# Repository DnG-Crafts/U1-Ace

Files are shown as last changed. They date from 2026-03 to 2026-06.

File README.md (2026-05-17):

# U1 Ace
Adding the Anycubic ACE to the U1 printer

<br><br>

https://www.youtube.com/watch?v=sk9fGzlz-C4 (https://www.youtube.com/watch?v=sk9fGzlz-C4)

https://www.youtube.com/watch?v=sk9fGzlz-C4<br>

<br><br>

# Extended Firmware

To use this you must install this version of the <a href=https://github.com/DnG-Crafts/U1-Ace/releases>extended firmware</a><br>
The original version provided by <a href=https://github.com/paxx12>paxx12</a> does not have the edits required to run this script.<br>

The extended firmware adds many features and fixes which you can read about <a href=https://snapmakeru1-extended-firmware.pages.dev/>HERE</a>

<br><br>

# RFID Tags

You can use NTAG 213,215 and 216 rfid tags for this mod, in the app navigate to settings and enable `Ace Format` to create tags that the ace can read.
<br>
App to write rfid tags for the U1:  <a href=https://github.com/DnG-Crafts/U1-RFID>U1-RFID - Github</a>
<br>

The android app is available on google play<br>
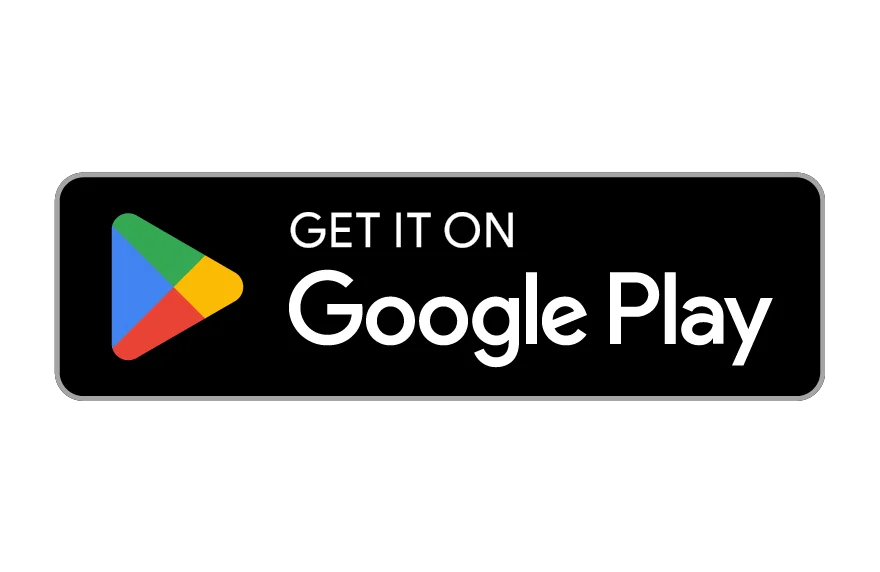
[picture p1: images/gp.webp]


<br><br>

# Enable Ace Mod

To enable the ace mod use a web brower and navigate to `http://PRINTER-IP/firmware-config/` and you will find the Ace Mod options<br>
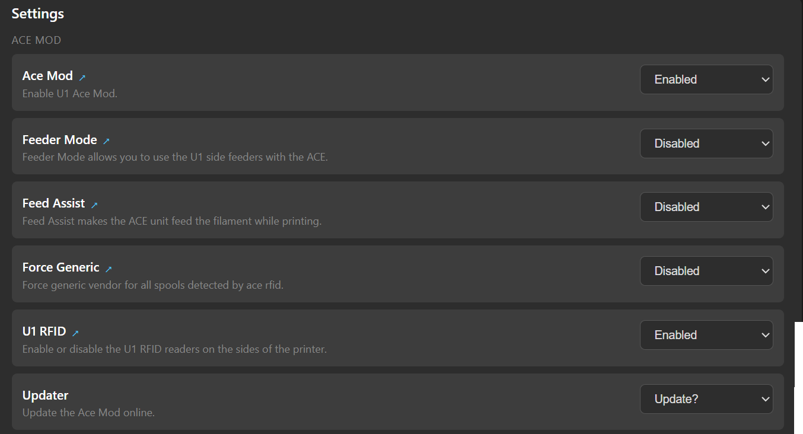
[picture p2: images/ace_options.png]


<br><br>

# Update Ace Mod

To update the ace mod use a web brower and navigate to `http://PRINTER-IP/firmware-config/` and you will find `Updater` in the Ace Mod options<br>
Select `Update Now` and the script will check for updates and apply them

<br><br>

# Klipper Settings

These are the default config values found in `/extended/mods/ace_device.cfg`, you do not need to modify these unless there is an issue.

```
[ace_device]

# these are the serial connection options and should not need to be modified

serial: /dev/serial/by-id/usb-ANYCUBIC_ACE_1-if00
baud: 115200

# speeds, 100 seems to be the maximum speed the ace will allow

feed_speed: 90
load_speed: 100
retract_speed: 25

# feeder mode allows you to leave the original U1 feeders on the printer
# and connect the ace to the U1 feeders on the sides of the printer.
# this allows you to still use the side spools if you needed.
# setting this to True will enable that functionality

enable_feeder_mode: False

# feed assist, setting this to False will disable feed assist

enable_feed_assist: True

# disable u1 rfid reader, setting this to True will disable the internal rfid reader of the printer
# this will stop the printer detecting spools on the sides of the printer while loading with ace.

disable_u1_rfid: False

# force generic vendor for all spools detected by rfid.
# this allows the filament to be selected in snapmaker orca with default generic filaments.

force_generic: False

# max temp for dryer

max_dryer_temperature: 55

# slot 1 2 3 4 are the individual numbered feeders/extruders
# this allows for different settings per slot

# the feed length is the distance from the ace to the u1
# the script detects the filament hitting the u1 sensor
# this only needs to be modified if the filament does not reach the u1 feeder

feed_length_slot1: 1000
feed_length_slot2: 1000
feed_length_slot3: 1000
feed_length_slot4: 1000

# the load length is the distance from the u1 feeder to the extruder
# these values should be fine unless you have extended the tubes

load_length_slot1: 850
load_length_slot2: 850
load_length_slot3: 850
load_length_slot4: 850

# the retract length is how far the ace retracts the filament when you
# unload the filament from the u1 touch screen menu
# if you do not like the loose filament on the spool set these values to 100 which
# is enough to clear the extruder but should not cause the loose filament issue shown in the video

retract_length_slot1: 100
retract_length_slot2: 100
retract_length_slot3: 100
retract_length_slot4: 100
```
<br><br>

# Filament Dryer

The filament dryer can be enabled or disabled from the fluidd or mainsail web ui using macros in the macro list or by using the following gcode commands in the console.

Starts the dryer for 240 minutes at 55 degrees celsius.
```
ACE_START_DRYING TEMPERATURE=55 DURATION=240
```

Stops the dryer, there is a cooldown time before the dryer stops after running this command.
```
ACE_STOP_DRYING
```

<br><br>

# Cable Setup

https://www.youtube.com/watch?v=DQsblPD1qpk (https://www.youtube.com/watch?v=DQsblPD1qpk)

https://www.youtube.com/watch?v=DQsblPD1qpk<br>

<br><br>

### Ace Pinout

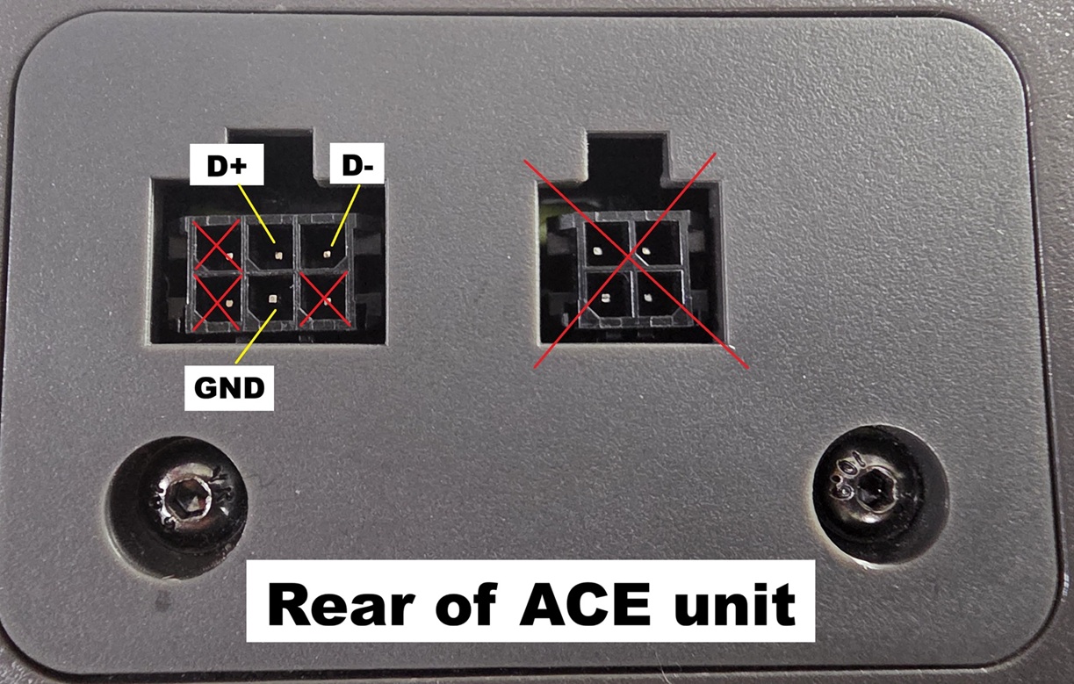
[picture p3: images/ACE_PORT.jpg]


<br><br>

# Feeder Setup

If you wish to use the side feeders then this is how you set them up.

https://www.youtube.com/watch?v=H58NYWm1mIg (https://www.youtube.com/watch?v=H58NYWm1mIg)

https://www.youtube.com/watch?v=H58NYWm1mIg<br>

<br>

<a href=https://github.com/DnG-Crafts/U1-Ace/tree/main/Ace%20Feeder%20Covers>Feeder Covers</a>

<br><br>

## Thankyou

Thankyou to the following people

<a href=https://github.com/paxx12>paxx12</a> for the extended firmware enabling the ability to mod the U1<br>
https://github.com/paxx12/SnapmakerU1-Extended-Firmware
<br><br>

<a href=https://github.com/Jookia>Jookia</a> for the raw data dumps from the ace<br>
https://github.com/printers-for-people/ACEResearch
<br><br>

<a href=https://github.com/utkabobr>utkabobr</a> for the python routines to keep the ace alive and responding<br>
https://github.com/utkabobr/DuckACE/
<br><br>

<a href=https://github.com/BlackFrogKok>BlackFrogKok</a> for the edit locations in the filament_feed.py to disable the factory feeders<br>
https://github.com/BlackFrogKok/SnapAce/
<br><br>

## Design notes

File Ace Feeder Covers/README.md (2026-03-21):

## Feeder Covers

<br>

Ace Feeder - Left<br>
Ace Feeder - Right<br>
<br>

These covers allow you to add m10 connectors to the U1 feeders.
The connectors are required because the ACE will push the filament during loading and feed assist so a secure connection is needed.<br><br>
I printed mine using PETG, white for the cover, black for the numbers and yellow translucent for the led light covers.

<br><br>
Ace Feeder Blank<br>
<br>

This cover is used to cover the feeder holes and cables when you remove the U1 feeders for the direct ace connection to the U1.<br>
You can print these out of any material as they are just covers and have no structural requirement.

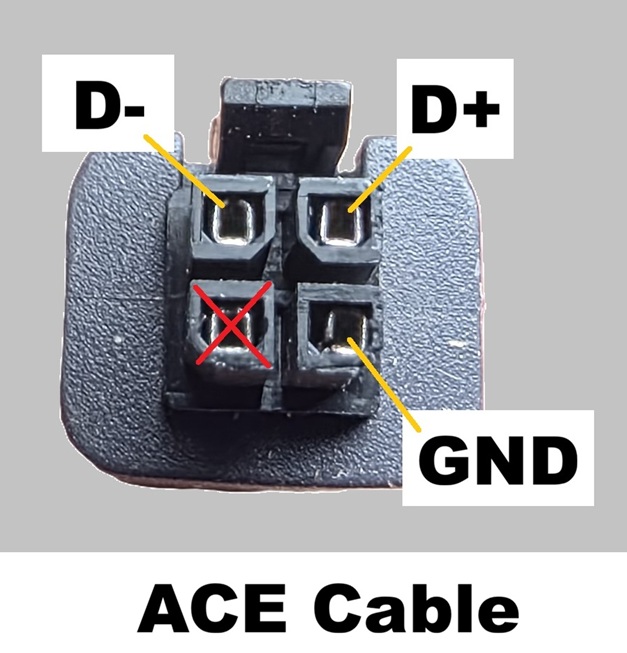
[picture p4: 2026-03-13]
images/ACE_CABLE.jpg

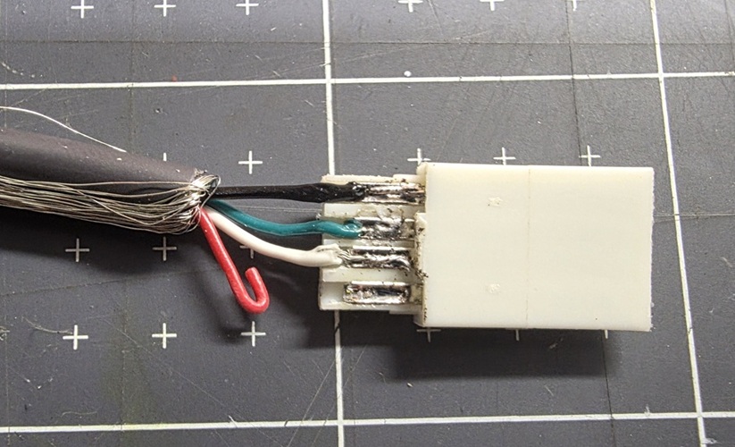
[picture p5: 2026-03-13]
images/Ace to A bottom.jpg

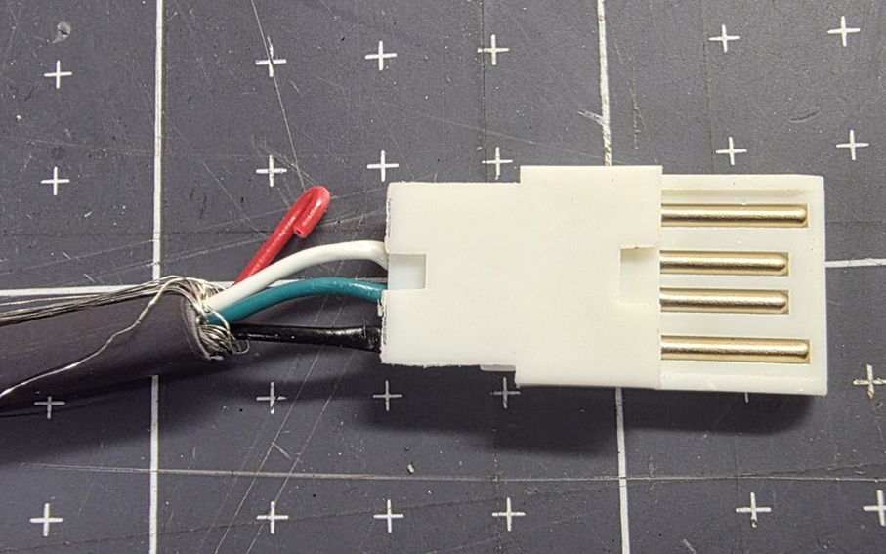
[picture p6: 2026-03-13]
images/Ace to A Top.jpg

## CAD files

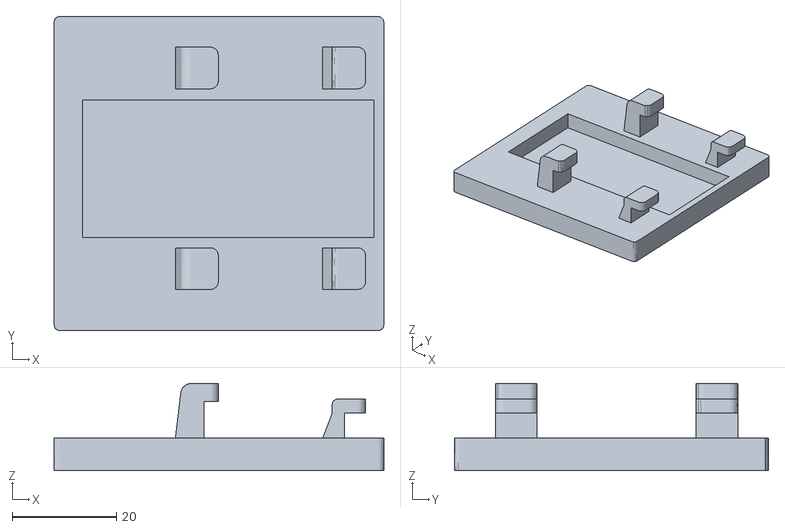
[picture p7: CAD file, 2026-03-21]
Ace Feeder Covers/Ace Feeder Blank.stl
63.2 x 60.3 x 16.7

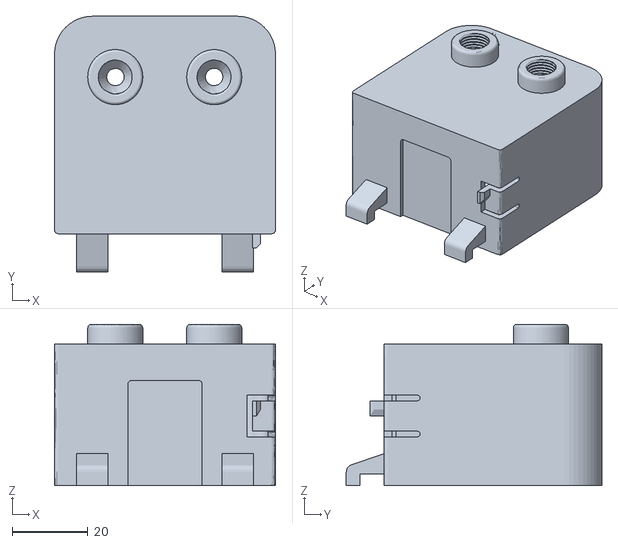
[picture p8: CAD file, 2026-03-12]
Ace Feeder Covers/Ace Feeder - Left.stl
58.2 x 67.3 x 42.4

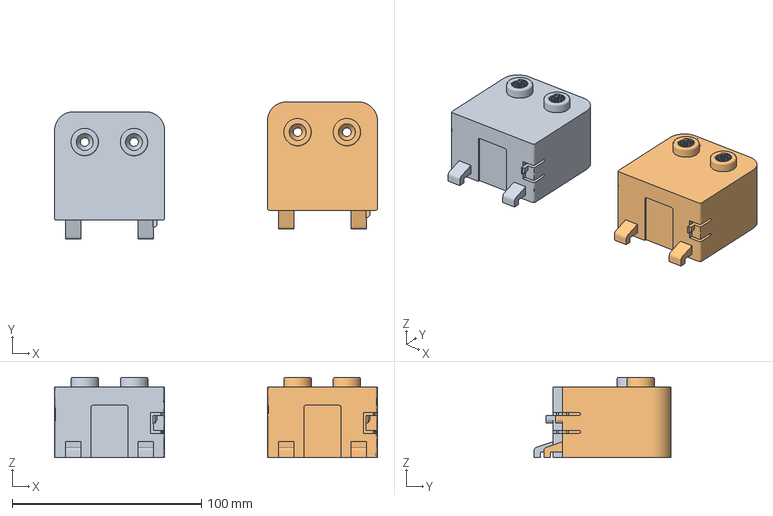
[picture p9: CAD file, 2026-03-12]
Ace Feeder Covers/Ace Feeders.3mf
170.7 x 72.5 x 42.4 mm
Ace Feeder - Left.stl
Ace Feeder - Right.stl

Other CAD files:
Ace Feeder Covers/Ace Feeder - Right.stl
Ace Feeder Covers/Ace Feeder - Left.obj
Ace Feeder Covers/Ace Feeder - Right.obj
Ace Feeder Covers/Ace Feeder Blank.obj

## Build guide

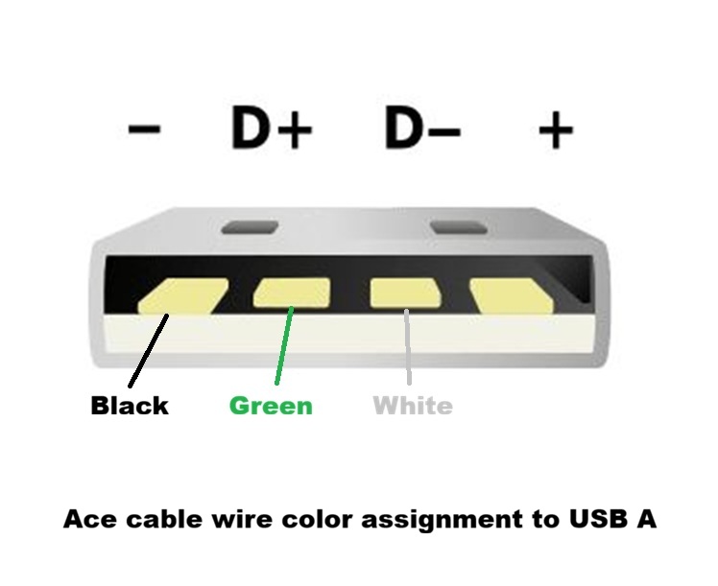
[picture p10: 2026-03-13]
images/USB A Wiring.jpg

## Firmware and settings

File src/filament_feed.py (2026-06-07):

import logging, copy, os
from . import pulse_counter


FEED_CHANNEL_NUMS                                   = 2
FEED_CHANNEL_1                                      = 0
FEED_CHANNEL_2                                      = 1

FEED_OK                                             = 'ok'
FEED_ERR                                            = 'general'
FEED_ERR_PARAMETER                                  = 'parameter'
FEED_ERR_TIMEOUT                                    = 'timeout'
FEED_ERR_NO_FILAMENT                                = 'no_filament'
FEED_ERR_RESIDUAL_FILAMENT                          = 'residual_filament'
FEED_ERR_MOTOR_SPEED                                = 'motor_speed'
FEED_ERR_WHEEL_SPEED                                = 'wheel_speed'
FEED_ERR_MOVE                                       = 'move'
FEED_ERR_MOVE_HOME                                  = 'move_home'
FEED_ERR_MOVE_SWITCH                                = 'move_switch'
FEED_ERR_MOVE_EXTRUDE                               = 'move_extrude'
FEED_ERR_CUSTOM_GCODE                               = 'custom_gcode'
FEED_ERR_DISTANCE                                   = 'distance'
FEED_ERR_STATE_MISMATCH                             = 'state_mismatch'
FEED_ERR_HEAT                                       = 'heat'

FEED_ACT_PRELOAD                                    = 'preload'
FEED_ACT_LOAD                                       = 'load'
FEED_ACT_UNLOAD                                     = 'unload'
FEED_ACT_MANUAL_FEED                                = 'manual_feed'
FEED_ACT_UPDATE_AUTO_MODE                           = 'update_auto_mode'
FEED_ACT_REMOVE_FILAMENT                            = 'remove_filament'
FEED_ACT_FILAMENT_RUNOUT                            = 'filament_runout'

FEED_STA_NONE                                       = 'none'
FEED_STA_INITED                                     = 'inited'
FEED_STA_WAIT_INSERT                                = 'wait_insert'
FEED_STA_PRELOAD_PREPARE                            = 'preload_prepare'
FEED_STA_PRELOAD_FEEDING                            = 'preload_feeding'
FEED_STA_PRELOAD_FINISH                             = 'preload_finish'
FEED_STA_PRELOAD_FAIL                               = 'preload_fail'
FEED_STA_LOAD_PREPARE                               = 'load_prepare'
FEED_STA_LOAD_HOMING                                = 'load_homing'
FEED_STA_LOAD_PICKING                               = 'load_picking'
FEED_STA_LOAD_HEATING                               = 'load_heating'
FEED_STA_LOAD_FEEDING                               = 'load_feeding'
FEED_STA_LOAD_EXTRUDING                             = 'load_extruding'
FEED_STA_LOAD_FLUSHING                              = 'load_flushing'
FEED_STA_LOAD_FINISH                                = 'load_finish'
FEED_STA_LOAD_FAIL                                  = 'load_fail'
FEED_STA_UNLOAD_PREPARE                             = 'unload_prepare'
FEED_STA_UNLOAD_HOMING                              = 'unload_homing'
FEED_STA_UNLOAD_PICKING                             = 'unload_picking'
FEED_STA_UNLOAD_HEATING                             = 'unload_heating'
FEED_STA_UNLOAD_HEAT_FINISH                         = 'unload_heat_finish'
FEED_STA_UNLOAD_DOING                               = 'unload_doing'
FEED_STA_UNLOAD_FINISH                              = 'unload_finish'
FEED_STA_UNLOAD_FAIL                                = 'unload_fail'
FEED_STA_MANUAL_PREPARE                             = 'manual_sta_prepare'
FEED_STA_MANUAL_HOMING                              = 'manual_sta_homing'
FEED_STA_MANUAL_PICKING                             = 'manual_sta_picking'
FEED_STA_MANUAL_PREPARE_FINISH                      = 'manual_sta_prepare_finish'
FEED_STA_MANUAL_PREPARE_FAIL                        = 'manual_sta_prepare_fail'
FEED_STA_MANUAL_HEATING                             = 'manual_sta_heating'
FEED_STA_MANUAL_EXTRUDING                           = 'manual_sta_extruding'
FEED_STA_MANUAL_EXTRUDE_FINISH                      = 'manual_sta_extrude_finish'
FEED_STA_MANUAL_EXTRUDE_FAIL                        = 'manual_sta_extrude_fail'
FEED_STA_MANUAL_FLUSHING                            = 'manual_sta_flushing'
FEED_STA_MANUAL_FLUSH_FINISH                        = 'manual_sta_flush_finish'
FEED_STA_MANUAL_FLUSH_FAIL                          = 'manual_sta_flush_fail'
FEED_STA_MANUAL_FINISH                              = 'manual_sta_finish'
FEED_STA_MANUAL_FAIL                                = 'manual_sta_fail'
FEED_STA_TEST                                       = 'test'

FEED_MANUAL_STAGE_PREPARE                           = 'prepare'
FEED_MANUAL_STAGE_EXTRUDE                           = 'extrude'
FEED_MANUAL_STAGE_FLUSH                             = 'flush'
FEED_MANUAL_STAGE_FINISH                            = 'finish'
FEED_MANUAL_STAGE_CANCEL                            = 'cancel'
FEED_UNLOAD_STAGE_PREPARE                           = 'prepare'
FEED_UNLOAD_STAGE_DOING                             = 'doing'
FEED_UNLOAD_STAGE_CANCEL                            = 'cancel'

FEED_LIGHT_PWM_CYCLE_TIME                           = 1
FEED_LIGHT_INDEXS                                   = ['RED', 'WHITE', 'ALL']

FEED_PORT_ADC_SAMPLE_TIME                           = 0.05
FEED_PORT_ADC_SAMPLE_COUNT                          = 4
FEED_PORT_ADC_REPORT_TIME                           = 0.300
FEED_PORT_ADC_VAL_THRESHOLD                         = 0.18
FEED_PORT_ADC_VAL_MODULE_EXIST                      = 0.9

FEED_MOTOR_DIR_IDLE                                 = 0
FEED_MOTOR_DIR_A                                    = 1
FEED_MOTOR_DIR_B                                    = 2

FEED_MOTOR_HARD_PROTECT_TIME                        = 2.5
FEED_MOTOR_SLIP_RATE                                = 0.7
FEED_MOTOR_REDUCTION_R                              = 33.0
FEED_WHEEL_CIRCUMFERENCE                            = 31.4159

FEED_PRELOAD_LENGTH                                 = 950.0
FEED_PRELOAD_TIMEOUT_TIME                           = 45
FEED_PRELOAD_MOTOR_MIN_SPEED                        = 200
FEED_PRELOAD_WHEEL_ERR_CNT_MAX                      = 3
FEED_PRELOAD_MOTOR_ERR_CNT_MAX                      = 2
FEED_LOAD_POSITION_X                                = 150
FEED_LOAD_POSITION_Y                                = 5
FEED_LOAD_LENGTH_MAX                                = 1100.0
FEED_LOAD_TIMEOUT_TIME                              = 60
FEED_LOAD_MOTOR_ERR_CNT_MAX                         = 20
FEED_LOAD_WHEEL_ERR_CNT_MAX                         = 20
FEED_LOAD_EXTRUDE_TIMES_MAX                         = 20
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

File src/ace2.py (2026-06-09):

# https://github.com/DnG-Crafts/U1-Ace
import serial, threading, time, logging, struct, queue, traceback, glob, copy, random, configparser
from datetime import datetime
from . import filament_protocol


_PREAMBLE       = b'\xff\xaa'
_END_MARKER     = 0xFE
_FLAG_REQUEST   = 0x00
_MAX_PAYLOAD    = 100

_CMD_DISCOVER_DEVICE       = 0
_CMD_ASSIGN_DEVICE_ID      = 1
_CMD_GET_STATUS            = 6
_CMD_FEED_OR_ROLLBACK      = 8
_CMD_STOP_FEED_OR_ROLLBACK = 9
_CMD_DRYING                = 11
_CMD_GET_FILAMENT_INFO     = 13
_CMD_SET_FEED_CHECK        = 19
_CMD_GET_TEMP              = 64

_FEED_MODE_FEED          = 0
_FEED_MODE_ROLLBACK      = 1
_FEED_MODE_FEED_ASSIST   = 2
_FEED_MODE_UNWIND_ASSIST = 3
_FEED_ASSIST_SPEED       = 10
_UNWIND_ASSIST_SPEED     = 0

_SLOT_READY              = 0
_SLOT_FEEDING            = 1
_SLOT_ROLLBACK           = 2
_SLOT_ASSISTING          = 3
_SLOT_ROLLBACK_ASSISTING = 4
_SLOT_PRELOADING         = 5
_SLOT_FEED_ERROR         = 129
_FILAMENT_EMPTY          = 0
_FILAMENT_IDENTIFIED     = 2

_VELOCITY_IDLE_THRESHOLD = 0.001
_FF_ACTIVE_PREFIXES = ('load_', 'unload_', 'preload_', 'manual_sta_')

_DRY_STATE_NAMES = {
    0: 'free', 1: 'starting', 2: 'keeping', 3: 'stopping',
    4: 'ptc_error', 5: 'ntc_error',
}
_SLOT_ERROR_BY_RAW = {
    129: 'feed_error', 130: 'rollback_error', 131: 'assist_error',
    132: 'preload_error', 133: 'stuck', 134: 'tangled', 135: 'motor_error',
}

ACE_ERROR_STATUSES = {
    'feed_error', 'rollback_error', 'preload_error',
    'stuck', 'tangled', 'motor_error', 'error',
}
_STATES_INCOMPATIBLE_WITH_ASSIST = {
    'ready', 'feeding', 'unwinding', 'preload', 'empty',
}


def _crc16_kermit(data):
    crc = 0xFFFF
    for b in data:
        crc ^= b
        for _ in range(8):
            crc = (crc >> 1) ^ 0x8408 if crc & 1 else crc >> 1
    return crc & 0xFFFF

def _pb_varint(value):
    r = bytearray()
    while value > 0x7F:
        r.append((value & 0x7F) | 0x80)
        value >>= 7
    r.append(value & 0x7F)
    return bytes(r)

def _pb_uint32(field, value):
    return _pb_varint((field << 3) | 0) + _pb_varint(int(value) & 0xFFFFFFFF)

def _pb_bool(field, value):
    return _pb_varint((field << 3) | 0) + _pb_varint(1 if value else 0)

def _pb_decode_varint(data, pos):
    result, shift = 0, 0
    while pos < len(data):
        b = data[pos]; pos += 1
        result |= (b & 0x7F) << shift
        if not (b & 0x80):
            return result, pos
        shift += 7
    return result, pos

def _pb_decode(data):
    fields = {}
    pos = 0; n = len(data)
    while pos < n:
        tag, pos = _pb_decode_varint(data, pos)
        fnum = tag >> 3; wtype = tag & 7
        if wtype == 0:   val, pos = _pb_decode_varint(data, pos)
        elif wtype == 1:
            if pos + 8 > n: break
            val = struct.unpack_from('<d', data, pos)[0]; pos += 8
        elif wtype == 2:
            ln, pos = _pb_decode_varint(data, pos)
            if pos + ln > n: break
            val = bytes(data[pos:pos + ln]); pos += ln
        elif wtype == 5:
            if pos + 4 > n: break
            val = struct.unpack_from('<f', data, pos)[0]; pos += 4
        else: break
        fields.setdefault(fnum, []).append((wtype, val))
    return fields

def _pb_first(fields, num, default=0):
    lst = fields.get(num)
    return lst[0][1] if lst else default

def _pb_str(fields, num, default=''):
    val = _pb_first(fields, num, default)
    if isinstance(val, (bytes, bytearray)):
        try: return val.decode('utf-8', errors='ignore')
        except: return default
    return val

def _build_packet(cmd, payload=b'', seq=1, flags=_FLAG_REQUEST):
    plen = min(len(payload), _MAX_PAYLOAD)
    inner = bytearray([flags & 0xFF, seq & 0xFF, (seq >> 8) & 0xFF,
                       cmd & 0xFF, plen & 0xFF])
    inner.extend(payload[:plen])
    crc = _crc16_kermit(bytes(inner))
    return _PREAMBLE + bytes(inner) + bytes([crc & 0xFF, (crc >> 8) & 0xFF, _END_MARKER])

def _parse_stream(buf):
    packets = []
    while True:
        if len(buf) < 10: break
        idx = buf.find(_PREAMBLE)
        if idx < 0: del buf[:-1]; break
        if idx > 0: del buf[:idx]; continue
        plen = buf[6]
        if plen > _MAX_PAYLOAD: del buf[:2]; continue
        total = 2 + 5 + plen + 2 + 1
        if len(buf) < total: break
        if buf[total - 1] != _END_MARKER: del buf[:2]; continue
        inner = bytes(buf[2:7 + plen])
        crc_r = buf[7 + plen] | (buf[8 + plen] << 8)
        if crc_r != _crc16_kermit(inner): del buf[:2]; continue
        packets.append({
            'cmd':     buf[5],
            'seq':     buf[3] | (buf[4] << 8),
            'flags':   buf[2],
            'is_resp': bool(buf[2] & 0x80),
            'payload': bytes(buf[7:7 + plen]),
        })
        del buf[:total]
    return packets, buf

def _slot_status_to_v1(slot_state, fil_state):
    if fil_state == _FILAMENT_EMPTY:                               return 'empty'
    if slot_state == _SLOT_FEEDING:                                return 'feeding'
    if slot_state == _SLOT_PRELOADING:                             return 'preload'
    if slot_state == _SLOT_ROLLBACK:                               return 'unwinding'
    if slot_state in (_SLOT_ASSISTING, _SLOT_ROLLBACK_ASSISTING):  return 'assisting'
    err = _SLOT_ERROR_BY_RAW.get(slot_state)
    if err:                                                        return err
    if slot_state >= _SLOT_FEED_ERROR:                             return 'error'
    return 'ready'

def _decode_status(payload):
    f = _pb_decode(payload)
    slots = []
    for _, sd in f.get(9, []):
        sf = _pb_decode(sd)
        ss = _pb_first(sf, 1, 0); fs = _pb_first(sf, 2, 0)
        slots.append({
            'status': _slot_status_to_v1(ss, fs),
            'rfid': 2 if fs == _FILAMENT_IDENTIFIED else (1 if fs != _FILAMENT_EMPTY else 0),
        })
    result = {
        'status': 'ready', 'slots': slots,
        'temp': _pb_first(f, 3, 0), 'humidity': _pb_first(f, 4, 0),
        'feed_assist_count': _pb_first(f, 7, 0),
    }
    if 2 in f:
        d = _pb_decode(f[2][0][1])
        result['dryer_status'] = {
            'status':      _DRY_STATE_NAMES.get(_pb_first(d, 1, 0), 'free'),
            'target_temp': _pb_first(d, 2, 0),
            'duration':    _pb_first(d, 3, 0),
            'remain_time': _pb_first(d, 4, 0),
        }
    return {'result': result}

def _decode_generic(payload):
    return {'code': _pb_first(_pb_decode(payload), 1, 0), 'msg': ''}

def _decode_temp(payload):
    f = _pb_decode(payload)
    def _flt(n):
        lst = f.get(n)
        if not lst: return 0.0
        try: return float(lst[0][1])
        except: return 0.0
    return {'result': {
        'box1_temp': _flt(1), 'box2_temp': _flt(2),
        'ptc1_temp': _flt(3), 'ptc2_temp': _flt(4),
        'env_temp':  _flt(5), 'env_humidity': _flt(6),
    }}
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

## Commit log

2026-03-10 Add Feeder Covers
    [Ace Feeder - Left.obj, Ace Feeder - Left.stl, Ace Feeder - Right.obj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]
2026-03-12 Update Covers
    Add more material to fitting screw section
    [Ace Feeder - Left.obj, Ace Feeder - Left.stl, Ace Feeder - Right.obj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]
2026-03-16 Update ace_device.py
    use gcode command to set filament info removing the requirement to edit filament_detect.py
2026-03-21 add covers
    add covers for feeder remove method
    [Ace Feeder Blank.obj, Ace Feeder Blank.stl]
2026-03-27 Update ace_device.py
    Fix serial not found in config error.
    Reset state after/on new print job.
    Add feeding logic for feed_assist disabled mode.
    Add retry count for initial feed in feeder_enabled mode to prevent endless loop of feeding if the filament binds on toolhead before sensor.
    Reduce default retract length to 100mm to stop filament unwinding off spool.
2026-04-10 updates
    modify update structure
    modify loading method in direct connect mode
    add option to disable u1 rfid readers
    [ace_device.cfg]
2026-04-13 updates
    fix code error
    add force generic option
    [ace_device.cfg]
2026-04-19 v2
    correct some filament values
2026-06-07 v140
    added v140 changes
    added ace2 support based on the work by hakimio at https://github.com/hakimio/U1-Ace/tree/ace2/src
    still work to be done for the rfid to show all fields
    `feeder mode` and `disable feed assist` stripped from ace 2 as they are not compatible.
    [ace2.py, filament_detect.py, filament_entangle_detect.py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]
2026-06-09 timing
    fix script exit timing
    [ace2.py]
